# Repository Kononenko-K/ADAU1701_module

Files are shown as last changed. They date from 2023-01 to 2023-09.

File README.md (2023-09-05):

# ADAU1701_module
SigmaDSP audio module with SigmaLink-USBi compatible programmer and USB digital isolator included
<br/>
<p align="center">
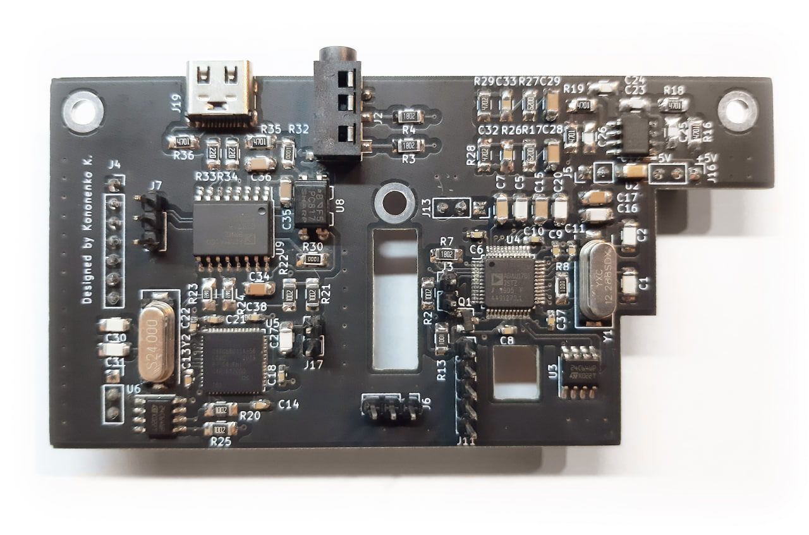
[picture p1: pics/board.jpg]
    
</p>

## Overview
This is a part of my yet unfinished project, that's why the board has such a peculiar shape. But it can be used as a standalone audio processing device with external PC control.
## [Hardware](Hardware)
The board features AUAD1701 SigmaDSP chip, CY7C68013A based USBi programmer and ADUM4160 USB isolator that prevents ground loops when the PC USB port and audio source share the same ground. It also has an active second order low pass reconstruction filter on the DAC outputs. The board can be programmed with SigmaStudio. There are [KiCad project](/Hardware), [Gerber files](/Hardware/gbr) and [PDF](/Hardware/project.pdf) avaliable.

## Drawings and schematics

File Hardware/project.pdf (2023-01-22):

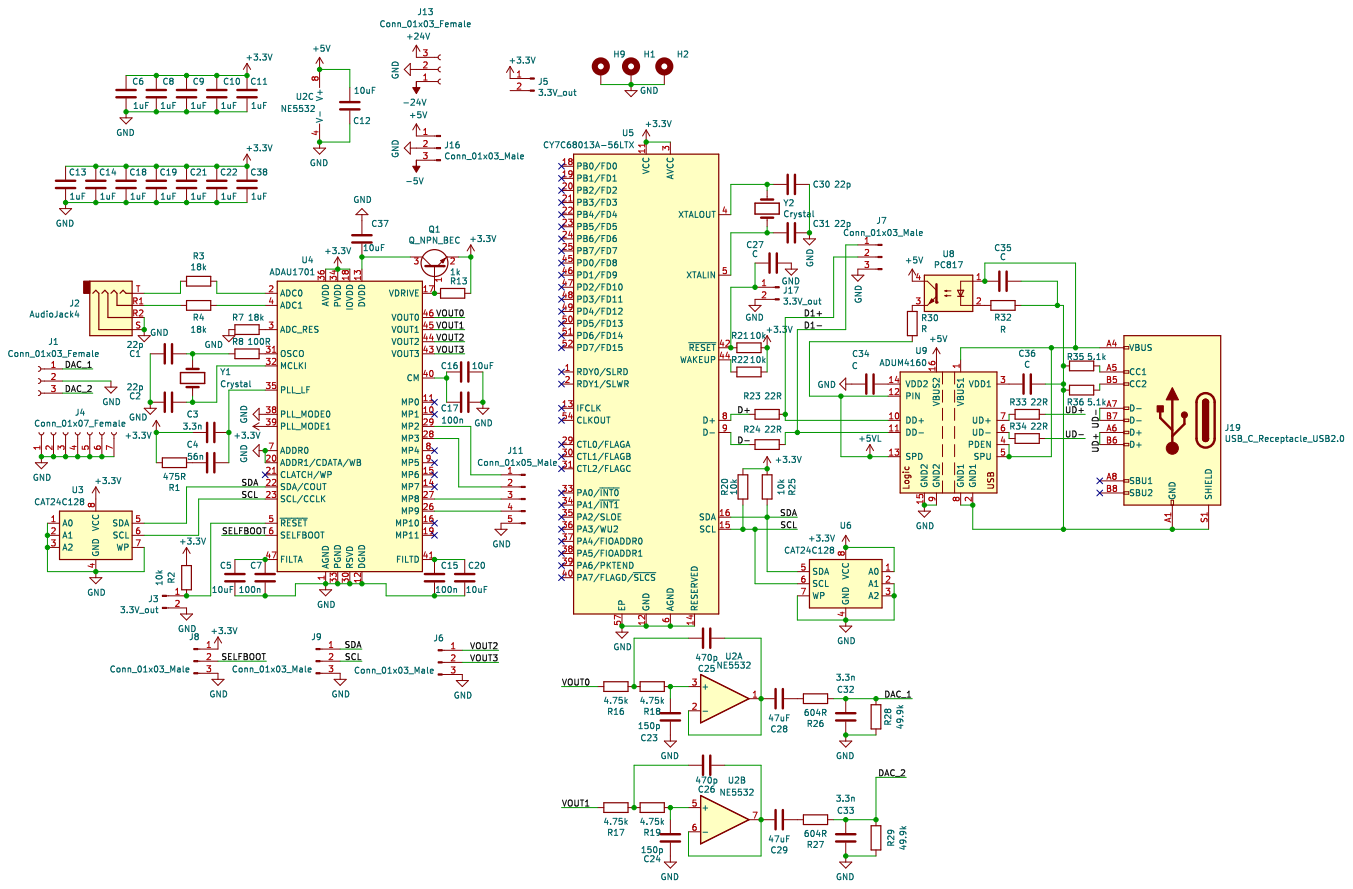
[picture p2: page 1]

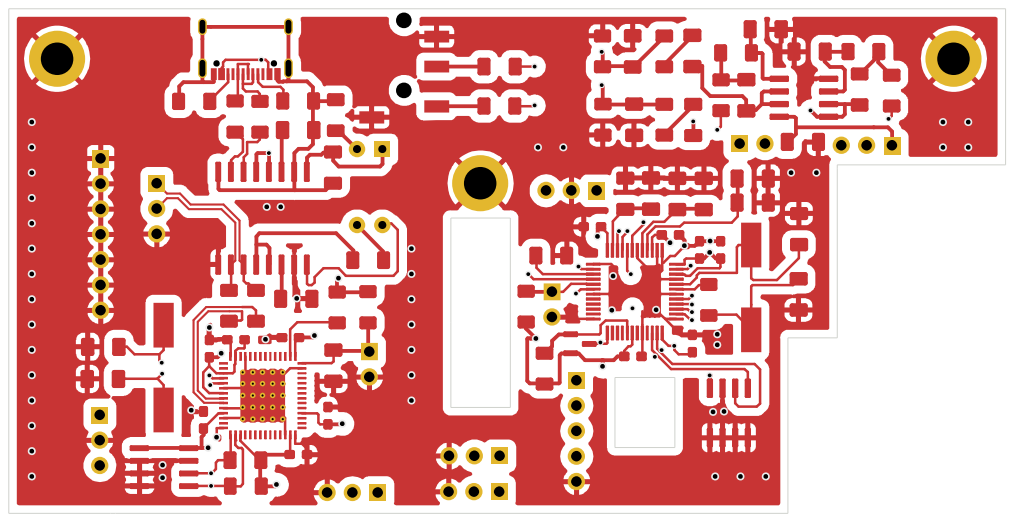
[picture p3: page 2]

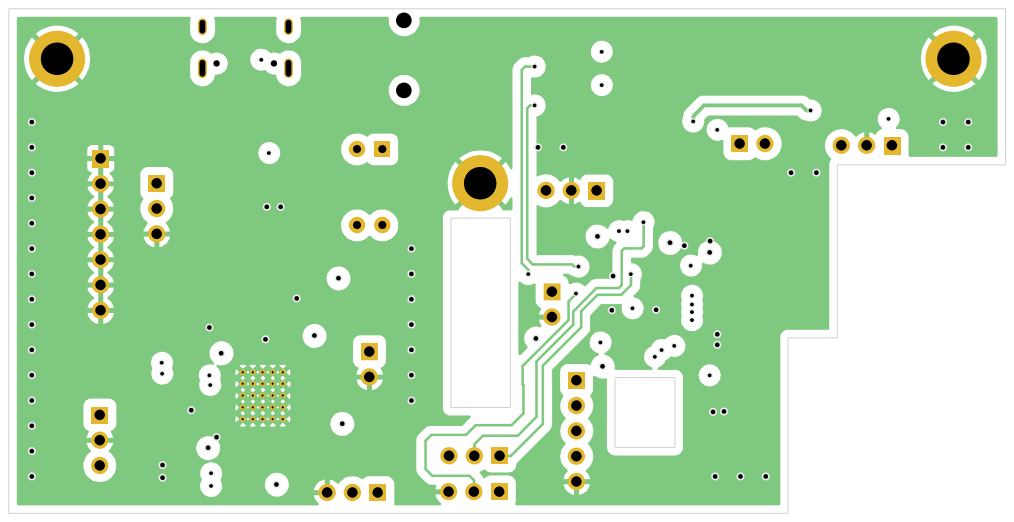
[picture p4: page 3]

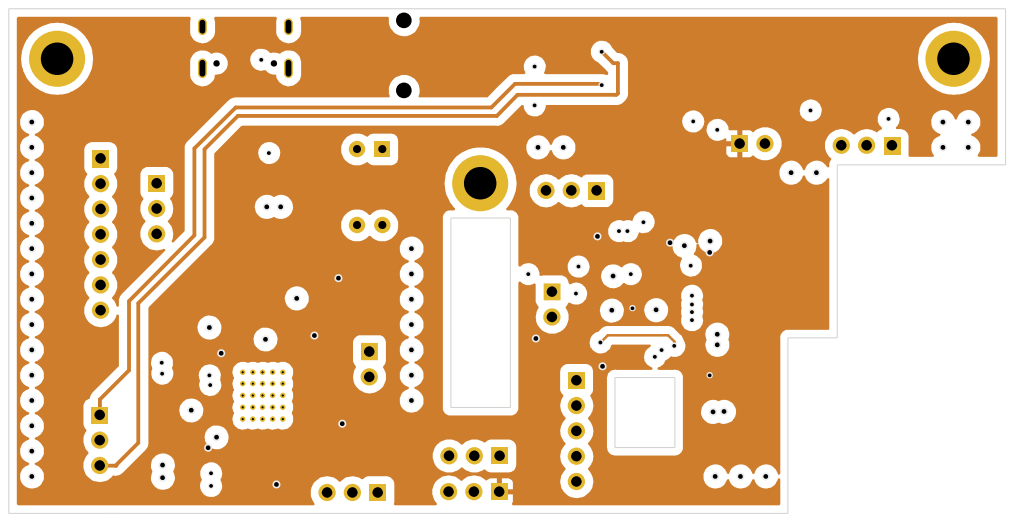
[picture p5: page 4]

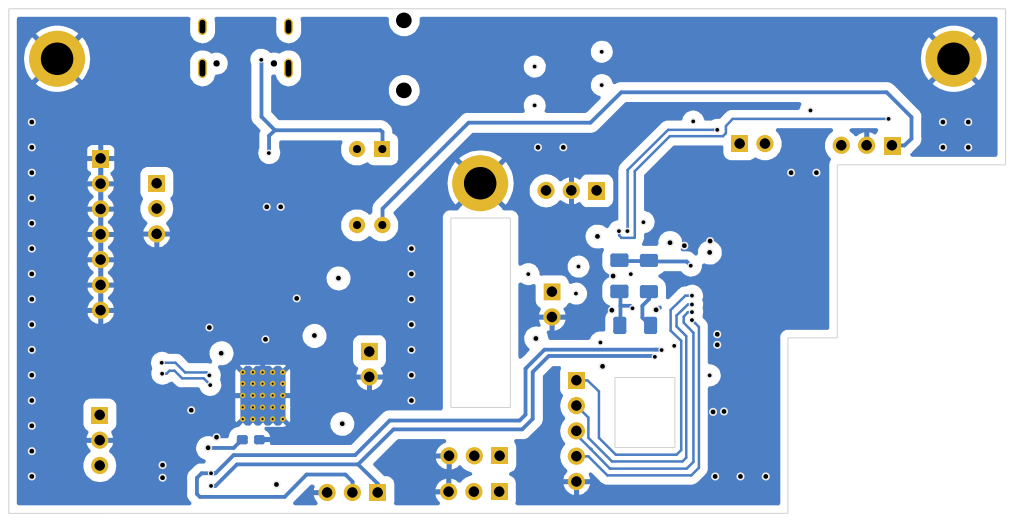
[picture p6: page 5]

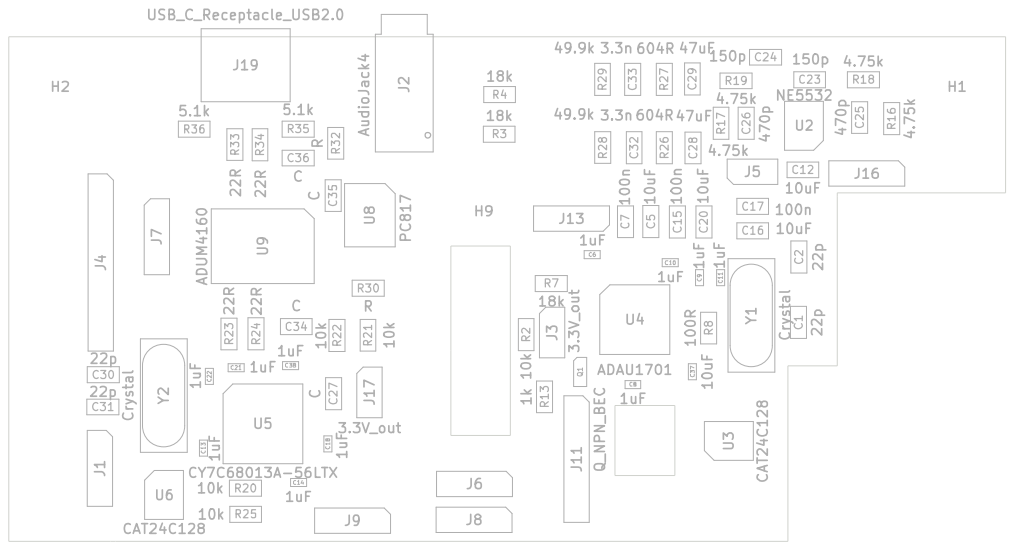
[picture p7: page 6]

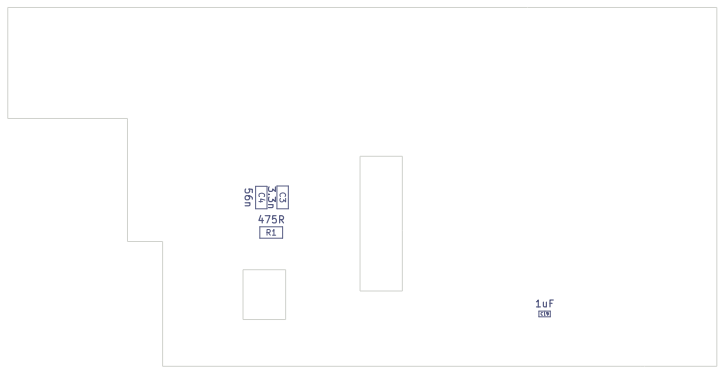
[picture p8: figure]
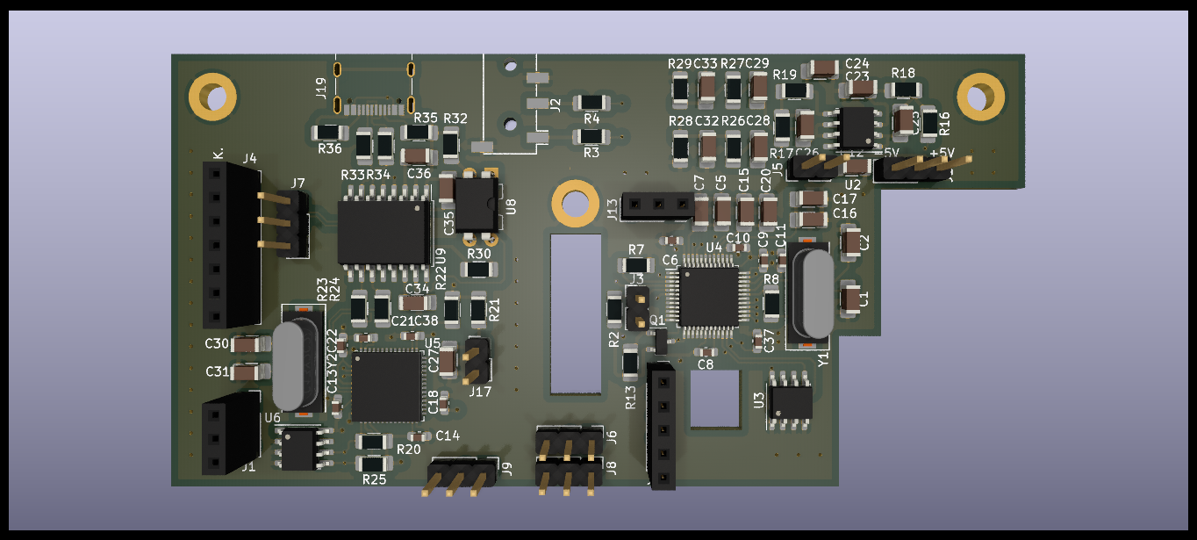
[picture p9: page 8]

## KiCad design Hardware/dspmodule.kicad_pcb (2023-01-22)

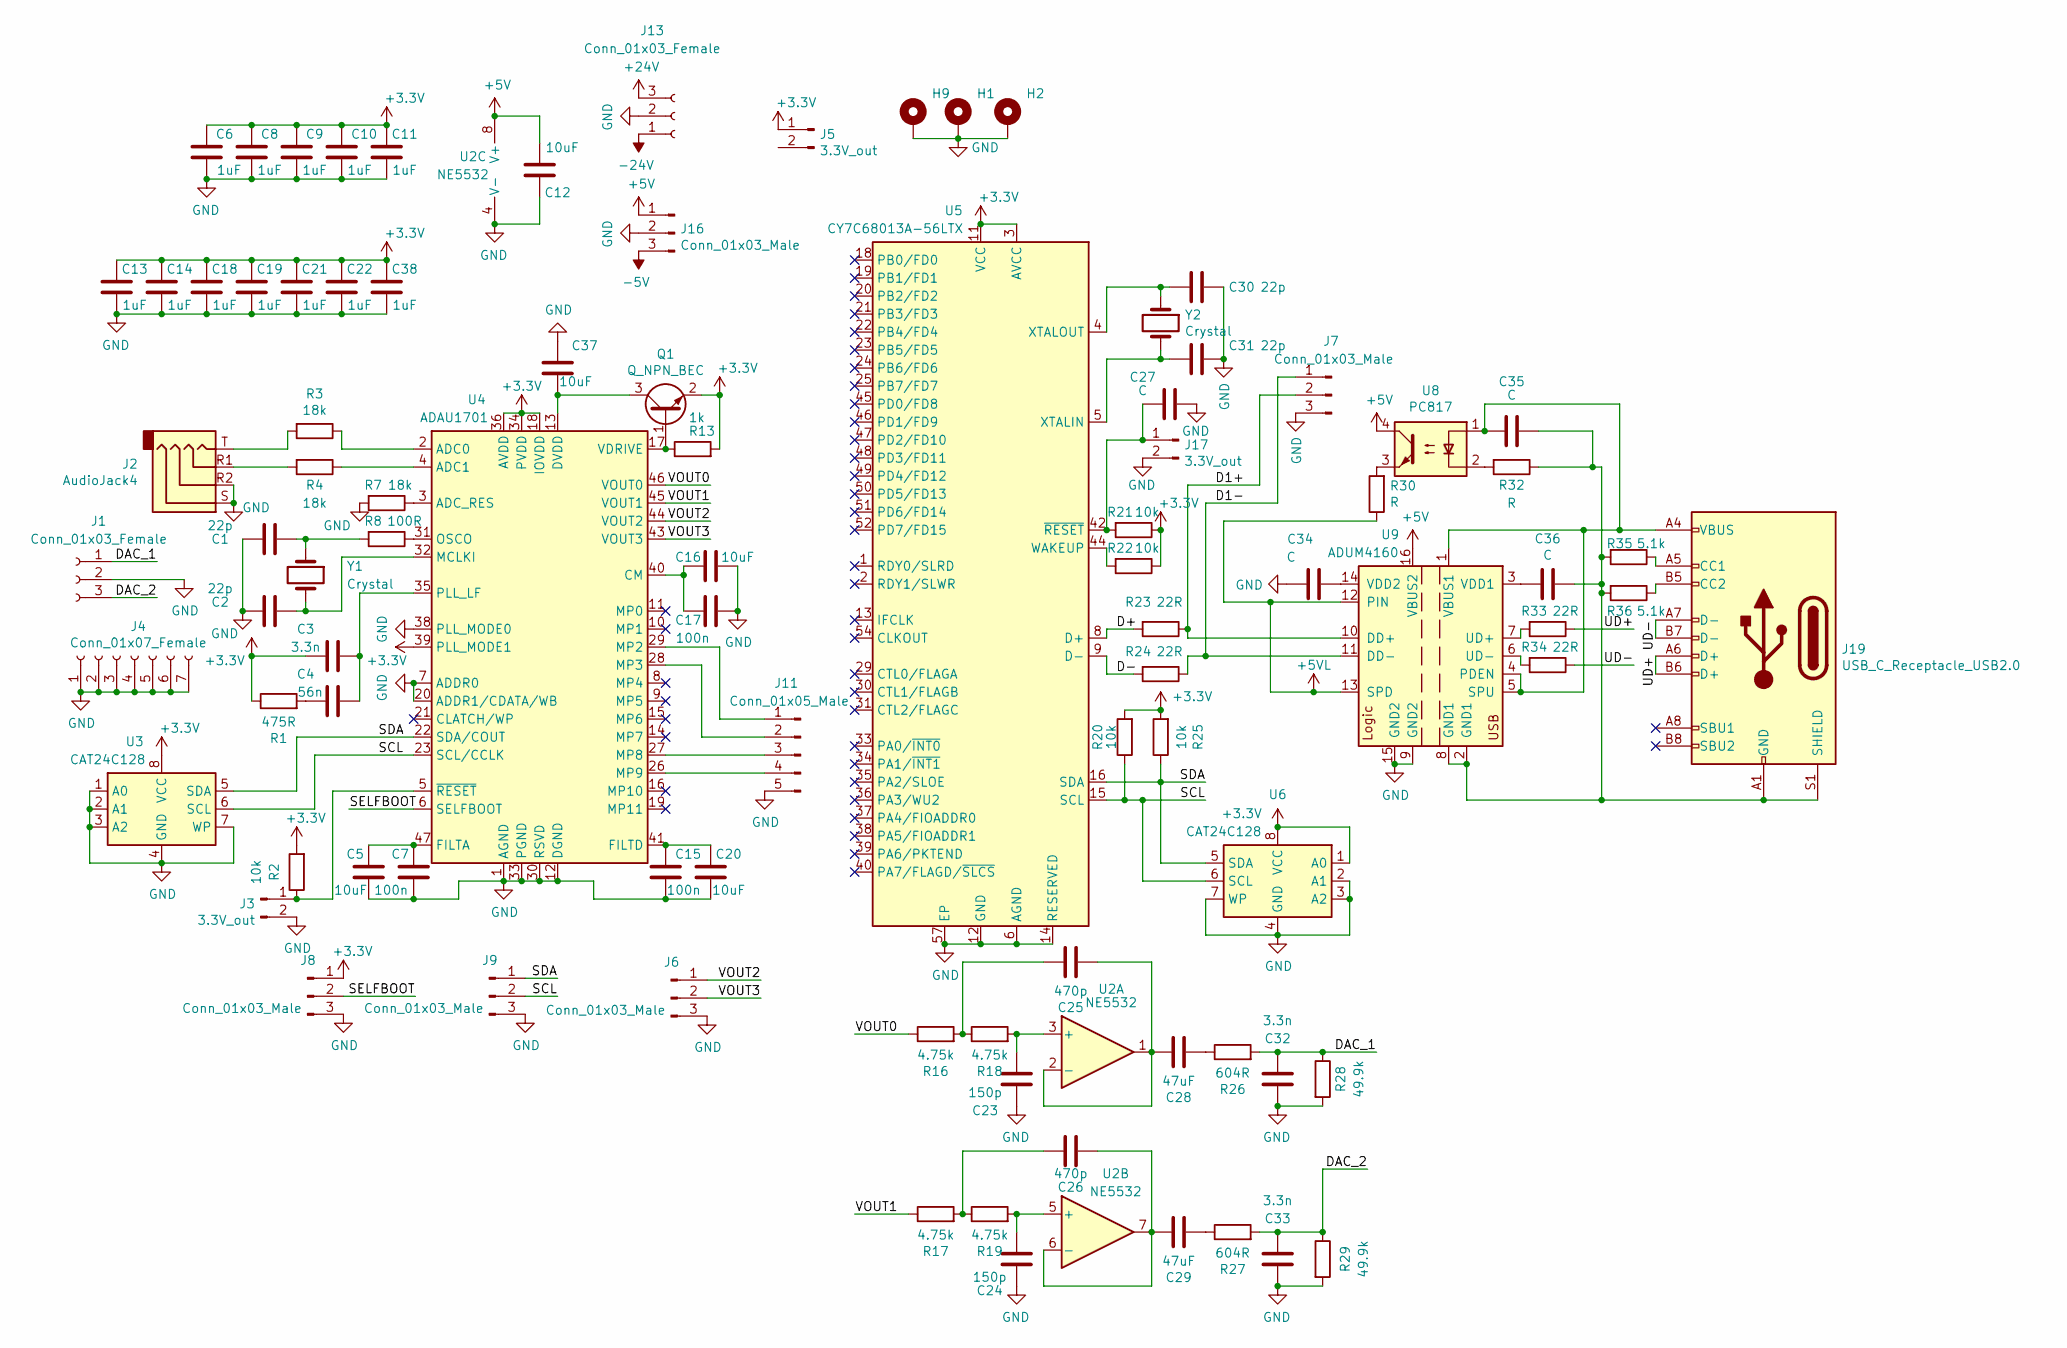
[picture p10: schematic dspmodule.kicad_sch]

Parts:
C1, C2, C30, C31: 22p; C_1206_3216Metric_Pad1.33x1.80mm_HandSolder
C3, C32, C33: 3.3n; C_1206_3216Metric_Pad1.33x1.80mm_HandSolder
C4: 56n; C_1206_3216Metric_Pad1.33x1.80mm_HandSolder
C5, C12, C16, C20: 10uF; C_1206_3216Metric_Pad1.33x1.80mm_HandSolder
C6, C8, C9, C10, C11, C13, C14, C18, C19, C21, C22, C38: 1uF; C_0603_1608Metric_Pad1.08x0.95mm_HandSolder
C7, C15, C17: 100n; C_1206_3216Metric_Pad1.33x1.80mm_HandSolder
C23, C24: 150p; C_1206_3216Metric_Pad1.33x1.80mm_HandSolder
C25, C26: 470p; C_1206_3216Metric_Pad1.33x1.80mm_HandSolder
C27, C34, C35, C36: C; C_1206_3216Metric_Pad1.33x1.80mm_HandSolder
C28, C29: 47uF; C_1206_3216Metric_Pad1.33x1.80mm_HandSolder
C37: 10uF; C_0603_1608Metric_Pad1.08x0.95mm_HandSolder
H1, H2, H9: MountingHole_Pad; MountingHole_3.2mm_M3_DIN965_Pad
J1, J13: Conn_01x03_Female; PinSocket_1x03_P2.54mm_Vertical
J2: AudioJack4; Jack_3.5mm_PJ320D_Horizontal
J3, J5, J17: 3.3V_out; PinHeader_1x02_P2.54mm_Vertical
J4: Conn_01x07_Female; PinSocket_1x07_P2.54mm_Vertical
J6, J7, J8, J9, J16: Conn_01x03_Male; PinHeader_1x03_P2.54mm_Vertical
J11: Conn_01x05_Male; PinSocket_1x05_P2.54mm_Vertical
J19: USB_C_Receptacle_USB2.0; USB_C_Receptacle_Palconn_UTC16-G
Q1: Q_NPN_BEC; SOT-23
R1: 475R; R_1206_3216Metric_Pad1.30x1.75mm_HandSolder
R2, R20, R21, R22, R25: 10k; R_1206_3216Metric_Pad1.30x1.75mm_HandSolder
R3, R4, R7: 18k; R_1206_3216Metric_Pad1.30x1.75mm_HandSolder
R8: 100R; R_1206_3216Metric_Pad1.30x1.75mm_HandSolder
R13: 1k; R_1206_3216Metric_Pad1.30x1.75mm_HandSolder
R16, R17, R18, R19: 4.75k; R_1206_3216Metric_Pad1.30x1.75mm_HandSolder
R23, R24, R33, R34: 22R; R_1206_3216Metric_Pad1.30x1.75mm_HandSolder
R26, R27: 604R; R_1206_3216Metric_Pad1.30x1.75mm_HandSolder
R28, R29: 49.9k; R_1206_3216Metric_Pad1.30x1.75mm_HandSolder
R30, R32: R; R_1206_3216Metric_Pad1.30x1.75mm_HandSolder
R35, R36: 5.1k; R_1206_3216Metric_Pad1.30x1.75mm_HandSolder
U2: NE5532; SOIC-8_3.9x4.9mm_P1.27mm
U3, U6: CAT24C128; SOIC-8_3.9x4.9mm_P1.27mm
U4: ADAU1701; LQFP-48_7x7mm_P0.5mm
U5: CY7C68013A-56LTX; QFN-56-1EP_8x8mm_P0.5mm_EP4.5x5.2mm_ThermalVias_TopTented
U8: PC817; DIP-4_W7.62mm
U9: ADUM4160; SOIC-16W_7.5x10.3mm_P1.27mm
Y1, Y2: Crystal; Crystal_SMD_HC49-SD

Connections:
+3V3: C3.2, C6.1, C8.1, C9.1, C10.1, C11.1, C13.1, C14.1, C18.1, C19.1, C21.1, C22.1, C38.1, J5.1, J8.1, Q1.2 (E), R1.1, R2.2, R13.2, R20.2, R21.1, R22.1, R25.2, U3.8 (VCC), U4.18 (IOVDD), U4.34 (PVDD), U4.36 (AVDD), U4.39 (PLL_MODE1), U4.48 (AVDD), U5.3 (AVCC), U5.7 (AVCC), U5.11 (VCC), U5.17 (VCC), U5.27 (VCC), U5.32 (VCC), U5.43 (VCC), U5.55 (VCC), U6.1 (A0), U6.8 (VCC)
+5V: C12.1, J16.1, U2.8 (V+), U8.4, U9.16 (VBUS2)
+5VL: R30.1, U9.12 (PIN), U9.13 (SPD)
+24V: J13.3
-5V: J16.3
-24V: J13.1
/D1+: J7.2, R23.1, U9.10 (DD+)
/D1-: J7.1, R24.1, U9.11 (DD-)
/D+: R23.2, U5.8 (D+)
/D-: R24.2, U5.9 (D-)
/DAC_1: C32.1, J1.1, R26.2, R28.1
/DAC_2: C33.1, J1.3, R27.2, R29.1
/SCL: J9.2, R20.1, U3.6 (SCL), U4.23 (SCL/CCLK), U5.15 (SCL), U6.6 (SCL)
/SDA: J9.1, R25.1, U3.5 (SDA), U4.22 (SDA/COUT), U5.16 (SDA), U6.5 (SDA)
/SELFBOOT: J8.2, U4.6 (SELFBOOT)
/UD+: J19.A6 (D+), J19.B6 (D+), R33.1
/UD-: J19.A7 (D-), J19.B7 (D-), R34.1
/VOUT0: R16.1, U4.46 (VOUT0)
/VOUT1: R17.1, U4.45 (VOUT1)
/VOUT2: J6.1, U4.44 (VOUT2)
/VOUT3: J6.2, U4.43 (VOUT3)
GND: C1.1, C2.1, C5.1, C6.2, C7.1, C8.2, C9.2, C10.2, C11.2, C12.2, C13.2, C14.2, C15.1, C16.2, C17.2, C18.2, C19.2, C20.1, C21.2, C22.2, C23.1, C24.1, C27.2, C30.2, C31.2, C32.2, C33.2, C34.2, C37.1, C38.2, H1.1, H2.1, H9.1, J1.2, J2.R2, J2.S, J3.2, J4.1, J4.2, J4.3, J4.4, J4.5, J4.6, J4.7, J6.3, J7.3, J8.3, J9.3, J11.5, J13.2, J16.2, J17.2, R7.2, R28.2, R29.2, U2.4 (V-), U3.1 (A0), U3.2 (A1), U3.3 (A2), U3.4 (GND), U3.7 (WP), U4.1 (AGND), U4.7 (ADDR0), U4.12 (DGND), U4.20 (ADDR1/CDATA/WB), U4.25 (DGND), U4.30 (RSVD), U4.33 (PGND), U4.37 (AGND), U4.38 (PLL_MODE0), U4.42 (AGND), U5.6 (AGND), U5.10 (AGND), U5.12 (GND), U5.14 (RESERVED), U5.26 (GND), U5.28 (GND), U5.41 (GND), U5.53 (GND), U5.56 (GND), U5.57 (EP), U6.2 (A1), U6.3 (A2), U6.4 (GND), U6.7 (WP), U9.9 (GND2), U9.15 (GND2)
unnamed: C1.2, R8.2, Y1.1
unnamed: C2.2, U4.32 (MCLKI), Y1.2
unnamed: C3.1, C4.1, U4.35 (PLL_LF)
unnamed: C4.2, R1.2
unnamed: C5.2, C7.2, U4.47 (FILTA)
unnamed: C15.2, C20.2, U4.41 (FILTD)
unnamed: C16.1, C17.1, U4.40 (CM)
unnamed: C23.2, R18.2, U2.3 (+)
unnamed: C24.2, R19.2, U2.5 (+)
unnamed: C25.1, R16.2, R18.1
unnamed: C25.2, C28.1, U2.1, U2.2 (-)
unnamed: C26.1, R17.2, R19.1
unnamed: C26.2, C29.1, U2.6 (-), U2.7
unnamed: C27.1, J17.1, R21.2, U5.42 (~RESET)
unnamed: C28.2, R26.1
unnamed: C29.2, R27.1
unnamed: C30.1, U5.4 (XTALOUT), Y2.1
unnamed: C31.1, U5.5 (XTALIN), Y2.2
unnamed: C34.1, U9.14 (VDD2)
unnamed: C35.1, C36.1, J19.A1 (GND), J19.A12 (GND), J19.B1 (GND), J19.B12 (GND), J19.S1 (SHIELD), R32.1, R35.2, R36.2, U9.2 (GND1), U9.8 (GND1)
unnamed: C35.2, J19.A4 (VBUS), J19.A9 (VBUS), J19.B4 (VBUS), J19.B9 (VBUS), U8.1, U9.1 (VBUS1), U9.4 (PDEN), U9.5 (SPU)
unnamed: C36.2, U9.3 (VDD1)
unnamed: C37.2, Q1.3 (C), U4.13 (DVDD), U4.24 (DVDD)
unnamed: J2.R1, R4.2
unnamed: J2.T, R3.2
unnamed: J3.1, R2.1, U4.5 (~RESET)
unnamed: J11.1, U4.29 (MP2)
unnamed: J11.2, U4.28 (MP3)
unnamed: J11.3, U4.27 (MP8)
unnamed: J11.4, U4.26 (MP9)
unnamed: J19.A5 (CC1), R35.1
unnamed: J19.B5 (CC2), R36.1
unnamed: Q1.1 (B), R13.1, U4.17 (VDRIVE)
unnamed: R3.1, U4.2 (ADC0)
unnamed: R4.1, U4.4 (ADC1)
unnamed: R7.1, U4.3 (ADC_RES)
unnamed: R8.1, U4.31 (OSCO)
unnamed: R22.2, U5.44 (WAKEUP)
unnamed: R30.2, U8.3
unnamed: R32.2, U8.2
unnamed: R33.2, U9.7 (UD+)
unnamed: R34.2, U9.6 (UD-)

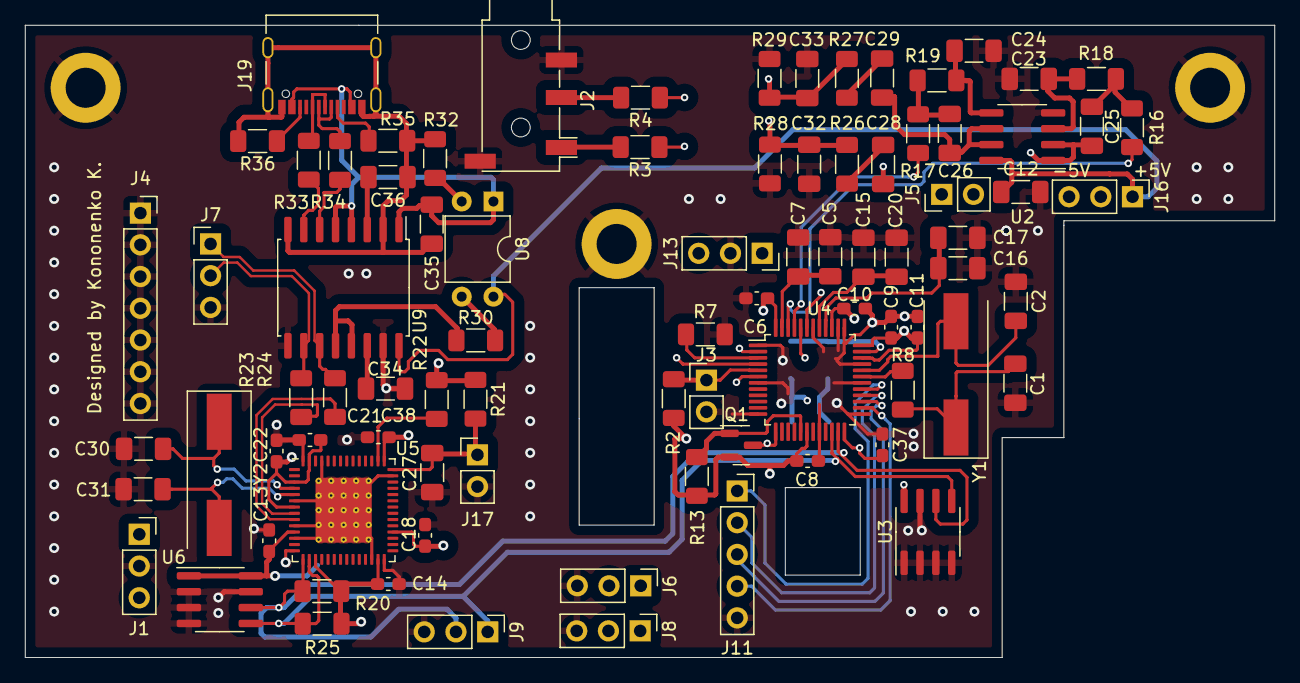
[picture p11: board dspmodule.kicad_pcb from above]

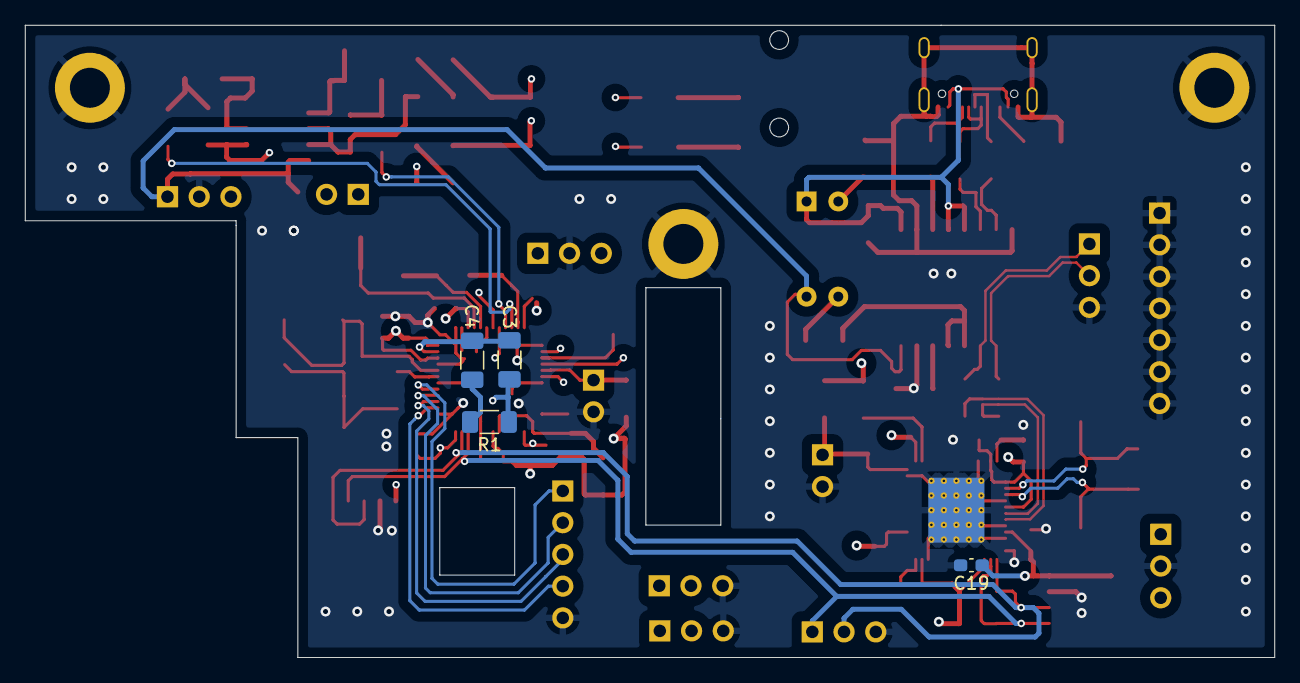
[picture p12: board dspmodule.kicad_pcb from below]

Board: 4 copper layers, 100.0 x 50.6 mm, 92 parts (4 on the bottom side), 61 nets.
